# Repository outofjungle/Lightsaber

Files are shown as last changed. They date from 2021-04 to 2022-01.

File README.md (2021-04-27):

# Lightsaber

## Wiring for the demo

The APA102 is 5V signaling. Please use appropriate logic level converter if working with 3.3V microcontrollers, like ESP8266 or ESP32. APA102 is controlled via the SPI bus.

| Lightsaber Pin | Microcontroller Pin |
|---|---|
| GND | GND |
| VCC | 5V |
| CI | SCK |
| DI | MOSI |

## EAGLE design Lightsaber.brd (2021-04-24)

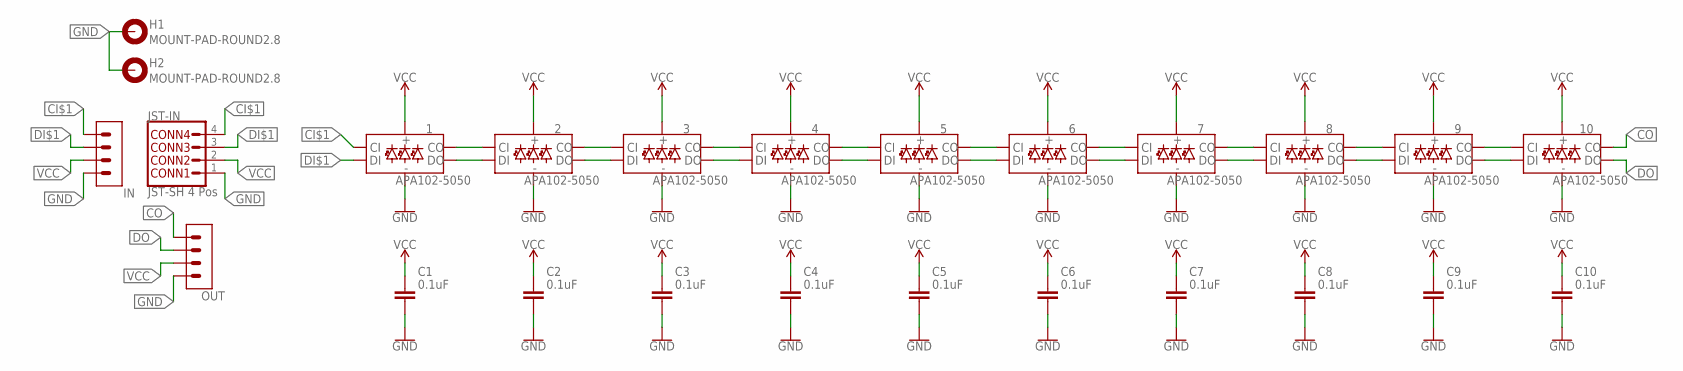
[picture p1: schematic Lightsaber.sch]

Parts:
1, 2, 3, 4, 5, 6, 7, 8, 9, 10: APA102-5050
C1, C2, C3, C4, C5, C6, C7, C8, C9, C10: 0.1uF; CAPC2012X110
H1, H2: MOUNT-PAD-ROUND2.8; 2,8-PAD
IN: 62000411121
JST-IN: JST-SH 4 Pos; JST04_1MM_VERT
OUT: 62000411121

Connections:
CI$1: 1.P2 (CI), IN.4, JST-IN.4
CI$2: 1.P5 (CO), 2.P2 (CI)
CI$3: 2.P5 (CO), 3.P2 (CI)
CI$4: 3.P5 (CO), 4.P2 (CI)
CI$5: 4.P5 (CO), 5.P2 (CI)
CI$6: 5.P5 (CO), 6.P2 (CI)
CI$7: 6.P5 (CO), 7.P2 (CI)
CI$8: 7.P5 (CO), 8.P2 (CI)
CI$9: 8.P5 (CO), 9.P2 (CI)
CI$10: 9.P5 (CO), 10.P2 (CI)
CO: 10.P5 (CO), OUT.4
DI$1: 1.P1 (DI), IN.3, JST-IN.3
DI$2: 1.P6 (DO), 2.P1 (DI)
DI$3: 2.P6 (DO), 3.P1 (DI)
DI$4: 3.P6 (DO), 4.P1 (DI)
DI$5: 4.P6 (DO), 5.P1 (DI)
DI$6: 5.P6 (DO), 6.P1 (DI)
DI$7: 6.P6 (DO), 7.P1 (DI)
DI$8: 7.P6 (DO), 8.P1 (DI)
DI$9: 8.P6 (DO), 9.P1 (DI)
DI$10: 9.P6 (DO), 10.P1 (DI)
DO: 10.P6 (DO), OUT.3
GND: 1.P3 (GND), 2.P3 (GND), 3.P3 (GND), 4.P3 (GND), 5.P3 (GND), 6.P3 (GND), 7.P3 (GND), 8.P3 (GND), 9.P3 (GND), 10.P3 (GND), C1.2, C2.2, C3.2, C4.2, C5.2, C6.2, C7.2, C8.2, C9.2, C10.2, H1.B2,8, H2.B2,8, IN.1, JST-IN.1, OUT.1
VCC: 1.P4 (VCC), 2.P4 (VCC), 3.P4 (VCC), 4.P4 (VCC), 5.P4 (VCC), 6.P4 (VCC), 7.P4 (VCC), 8.P4 (VCC), 9.P4 (VCC), 10.P4 (VCC), C1.1, C2.1, C3.1, C4.1, C5.1, C6.1, C7.1, C8.1, C9.1, C10.1, IN.2, JST-IN.2, OUT.2

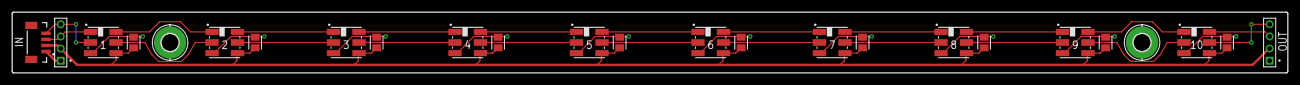
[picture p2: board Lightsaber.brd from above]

Board: 2 copper layers, 210.0 x 10.0 mm, 25 parts (0 on the bottom side), 24 nets.

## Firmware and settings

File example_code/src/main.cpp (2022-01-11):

#include <Arduino.h>
#include <FastLED.h>

#if TARGET_CHIPSET == ATTINY85
#define CLOCK_PIN 2
#define DATA_PIN 0
#elif TARGET_CHIPSET == ESP8266
#define CLOCK_PIN 14
#define DATA_PIN 13
#elif TARGET_CHIPSET == ESP32
#define CLOCK_PIN 18
#define DATA_PIN 23
#endif

#define NUM_LEDS 10
#define DELAY 42
#define DELTA_HSV_SHIFT 8

CRGB leds[NUM_LEDS];

void setup()
{
  FastLED.addLeds<APA102, DATA_PIN, CLOCK_PIN, BGR>(leds, NUM_LEDS);
  FastLED.setBrightness(0xFF);
}

void update_color()
{
  static uint8_t hue = 0;
  static int8_t pos = 0;
  static int8_t dir = 1;

  hue += DELTA_HSV_SHIFT;

  fill_solid(leds, NUM_LEDS, CRGB::Black); // set all LEDs to black
  leds[pos] = CHSV(hue, 0xFF, 0xFF);       // set the current pos to computed color (saturation=0xFF, value=0xFF)
  blur1d(leds, NUM_LEDS, 0x20);            // blend color to nearest neighbors
  FastLED.show();

  pos = pos + dir;
  if (pos <= 0)
  {
    pos = 0;
    dir = dir * -1;
  }
  else if (pos >= NUM_LEDS)
  {
    pos = NUM_LEDS - 1;
    dir = dir * -1;
  }
}

void loop()
{
  static bool do_update;
  static uint32_t last_updated;

  if (do_update)
  {
    update_color();

    last_updated = millis();
    do_update = false;
  }

  if (millis() - last_updated > DELAY)
  {
    do_update = true;
  }
}

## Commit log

2021-04-21 Rounded corners
    [Lightsaber.brd]
2021-04-22 fixed silkscreen for names/values
    [Lightsaber.brd, Lightsaber.sch]
2021-04-22 added info labels to the silkscreen
    [Lightsaber.brd, Lightsaber.sch]
2021-04-22 final fixes and gerber file generation
    [Lightsaber.brd]
2021-04-22 added tented vias
    [Lightsaber.brd]
2021-04-24 Fix ground trace width
    [Lightsaber.brd]
2021-05-04 updated test code to cycle thru LEDs and colors
2021-05-04 fixed a hsv bug and minor improvements
    [main.cpp]

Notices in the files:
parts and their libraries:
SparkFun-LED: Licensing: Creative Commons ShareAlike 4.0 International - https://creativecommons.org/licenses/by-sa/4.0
